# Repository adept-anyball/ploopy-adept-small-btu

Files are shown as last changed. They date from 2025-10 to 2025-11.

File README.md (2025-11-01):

# ploopy-adept-small-btu

> [!TIP]
> Making these models take time and investment. I would like to keep them free, so if you like them, please consider to [buy me a coffee](https://www.paypal.com/donate/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)

A small Ploopy Adept case with BTU bearings



I really like the Ploopy Adept hardware, but I wanted something smaller and lower to use between the two parts of my split keyboard. So I created this case for the Ploopy Adept, which is pretty small and low.

There are 4 versions:

- [V1](./v1-deprecated/): for a 34mm trackball. This is the initial version and it is deprecated. I would not recommend going for it. I am just keeping it here in case anyone still needs it. It will go at some point.

- [V2](./v2/): for a 38.1mm (1.5 inch) trackball. This version is still good to use and it can also fit the 34mm trackball support from V3.

- [V3](./v3/): which has trackball supports for both 34mm and 38.1mm trackballs. It is somewhat the same as V2, but with aesthetical improvements and slight improvements on the buttons too. In V3, the top and bottom of the case are the same, whether you choose to use a 34mm or a 38.1mm trackball, but you need to choose the correct track ball support.

- [V4 Slim](./v4/): which has trackball supports for both 34mm and 38.1mm trackballs. It is a much slimmer version of the v3, with aesthetical improvements e.g. all front buttons have the same size. The top and bottom of the case are the same, whether you choose to use a 34mm or a 38.1mm trackball, but you need to choose the correct track ball support.

- [V5 Slim Angled](./v5/): which has trackball supports for both 34mm trackballs. It builds on the V4, but has a 3 degree angle, which improves the buttons a lot.

I would obviously recommend going for the V5, but it is up to you to choose. You can find assembly instructions by browsing into the folder of each of the versions.

If you would like to user other bearings instead of BTUs, there are adapters available [here](https://github.com/adept-anyball/mod/tree/master/adapters).

Enjoy it! Feedback and contributions are very welcome.

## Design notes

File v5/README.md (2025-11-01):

# V5- SLIM - ANGLED - 34mm trackball

It is essentially the same as the v4, so all the same instructions apply.

The differences are from this and the v4 slim flat version are:

- It has a 3 degree angle, so the front buttons are slightly higher
- The buttons are improved: more stable and less dead areas

> [!IMPORTANT]
> The STEP and STL files contain top, bottom and ball support for a 34mm ball.
> So, please remember to split the into objects before printing

I didn't have time to create a 38mm ball support yet, not sure if it will be done and not when.
For now, if you want to use a 38mm ball, you can use the 38mm trackball support from the v4 slim.

There are 2 versions of the v5:

- v5-slim-angled-34mm-full: a more squared versions, with the same screw style of the v4

> [!IMPORTANT]
> The **v5-slim-angled-34mm-rounded-full** requires different screws. **It uses 4x M2.5x7mm screws**.

- v5-slim-angled-34mm-rounded-full: improved buttons, screws on the bottom (instead of on the sides) and more rounded corners.

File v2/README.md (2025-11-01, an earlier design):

# V2 - 38.1mm trackball (1.5 inch)



This design consists of 4 parts, see the mechanicals section for the explanation. It prints without supports and require minimal assembly.
Even though the top part consists of 2 separate parts, it looks like a unibody part after assembly.

## Mechanicals



1. v2-38mm-top-buttons.step: the top frame with buttons and a cut-out for the track ball support insert (part #2)
2. v2-38mm-top-trackball.step: the trackball insert where the bearings and the trackball should be placed. It fits in the cut-out of the part #1
3. v2-38mm-bottom.step: the bottom part of the case, where the pcb should be placed
4. (OPTIONAL) v2-38mm-cover-keycaps.step: a cover to the top, so you can add another finish to the top of the trackball and keycaps. These can be printed in different colors for some extra personalization and/or with a smaller layer height for a smoother surface :)

## Printing instructions/remarks

**The models print without the need of any support. Using supports will likely ruin the print, unless you really know what you are doing!**

I have printed it in both PLA and PETG and both work fine. I recommended using a layer height of 0.2mm.

Part #1 should be printed with the buttons facing the build plate (so upside-down), and the remaining parts should be printed in the regular orientation.

## BoM

- [A Ploopy Adept kit](https://ploopy.co/shop/adept-trackball-full-kit/)
- 4 M2 x 4mm thread inserts. I used [these ones](https://www.amazon.de/dp/B088QJG676/ref=pe_27091401_487027711_TE_SCE_dp_i1?th=1)
- 4 M2 x 10mm countersunk screws. I used [these ones](https://www.amazon.de/-/en/gp/product/B0D6QXRH6H/ref=ppx_od_dt_b_asin_title_s00?ie=UTF8&th=1)
- A 38.1mm trackball (1.5 inch). I have used my Ploopy Nano trackball. You can either buy a billiard ball or something more fit for purpose like this ones from [gamingtrackball](https://www.gamingtrackball.com/products/yellow-and-silver-add-on-balls)
- 3 BTU bearings [KU-B8-OFK R053010810](https://store.boschrexroth.com/BALL-TRANSFER-UNIT_R053010810?cclcl=en_MY)
- (OPTIONAL) Superglue to put some of the parts together

## Assembly

See Mechanicals section above for the part numbers.

1. Print all the parts
2. (OPTIONAL) Glue part #4 to part #1
3. Insert the 3 BTU bearings on part #2. There is some clearance, so you should not need to push very hard, only a bit of force is necessary.
4. Insert part #2 into the cut-out of part #1, making sure that the flat part of the optics cut-out is the round edge of the case (see picture below). Make sure that the bottom aligns perfectly. The part should stay in place, but you may choose to glue them together, if you prefer.



5. Insert the 4 thread inserts in the 4 holes on the corners of the bottom of part #1, using a heat-insertion tool or a soldering iron. I would recommend a proper heat-insertion tool like [this one](https://www.amazon.de/dp/B0C5CC2QB9/ref=pe_27091401_487027711_TE_SCE_dp_i1), since these thread inserts are quite small
6. Place the PCB in the sunken area of part #3
7. Place the top part over the bottom part making sure that the optics are aligned correctly. The bottom part has some small guides that should help placing the top correctly and holding it in place.
8. Screw the bottom to the top. Start by screwing all the screws half in and then tighten them up.

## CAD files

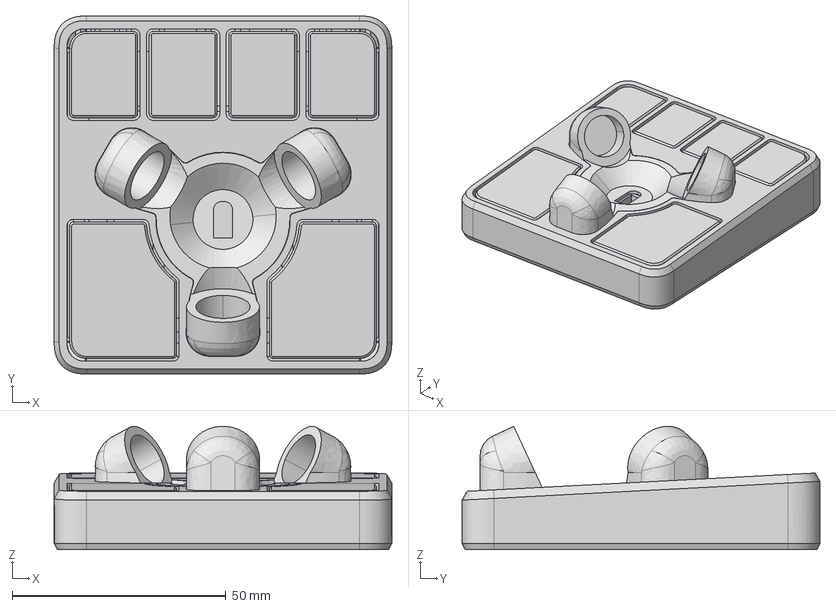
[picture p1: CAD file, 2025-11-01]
v5/v5-slim-angled-34mm-rounded-full.step
79.0 x 83.8 x 28.9 mm

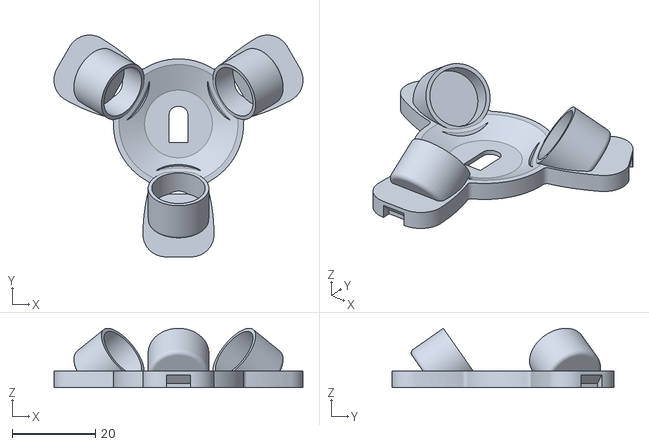
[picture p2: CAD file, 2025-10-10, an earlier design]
v4/generation script/trackball support generator - bosch btu, 21.8mm deflected.stl
59.8 x 53.3 x 14.3

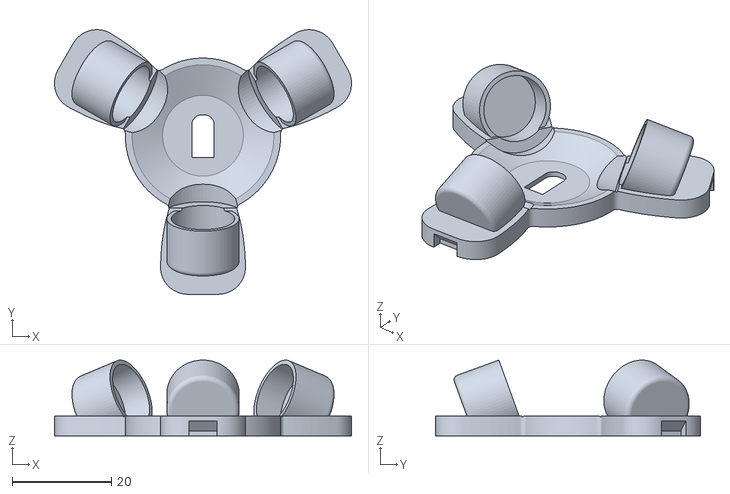
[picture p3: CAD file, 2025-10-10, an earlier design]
v4/generation script/trackball support generator - bosch btu, 25mm ball.stl
59.8 x 53.3 x 15.3

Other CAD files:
v5/v5-slim-angled-34mm-full.step
v4/generation script/trackball support generator.scad
v5/v5-slim-angled-34mm-full.stl
v5/v5-slim-angled-34mm-rounded-full.stl

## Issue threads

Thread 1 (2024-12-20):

Not an issue, just wanted to thank you for this

whosdev, 2024-12-20:
Heya, Not an issue at all I just wanted to thank you for this awesome job. I recently bought an Adept, and while I loved it, I found it too tall for my hand, somehow, I loved this version you made. Is there a way to "make room" to use the 44mm ball that comes with it while still being somewhat slim? also which BTU did you use?

fabricio-bastian, 2024-12-20:
Hi there. Glad to hear that you liked it :)
I did consider using a larger ball while I was designing it. My choice of using a smaller ball was a bit about aesthetics, but also because, in my personal opinion, the 44mm ball has too much momentum on the BTUs. Also, it would compromise a bit on the usability of the buttons, because there is not that much room.
I think that the perfect size would be the ploopy nano trackball. Which is probably where I'm going next with this (I don't know when though :)). I just found it a bit hard to source trackballs on that size that look nice...

whosdev, 2024-12-20:
I see, thank you again! I'll both print this one and try to change the ball size, I do have a few 34mm perixx here as well, But never used the btu's so I've no idea on how it affect the momentum.
I don't mind the trackball getting a bit bigger overall (I mean, in size, but not in height heh).

fabricio-bastian, 2024-12-20:
Sounds great. Do you want access to the design file? I would love to see the results if you play with the design :)

I have used onshape and I can share it with you, so you can play with it. The CAD history is not particularly clean though 😅.

If you go for the 44mm ball, you will likely get something that is about as tall as the original Adept, with the exception of the front buttons, since this design is not slanted as the original is.

whosdev, 2024-12-21:
Yeah sure! I would love to have the design files! But now it makes sense, maybe the ball would be TOO high, and it wouldn't be that much usable, hmmmmmmmm, now I am not sure If it's a great idea! I was planning on using chinese BTU, which aren't that great, but are the ones I can buy hahahha. So I think maybe with a bigger ball, it won't have that much momentum.
 But I wasn't thinking about the height of the ball and how hard/easy it will be to push the buttons. damn, I'm dumb.

fabriciobastian, 2025-01-04:
Hey again. I did a new version with a 1.5inch ball (same size as the nano), which you may like. I have uploaded the step files, which are easier to modify. The trackball is still quite low IMO, I can still use it in a natural hand position without any need for wrist rests. Check it out :)

Closed 2025-01-04.

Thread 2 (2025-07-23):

Feature Request: Different Ball sizes

vaughnmonkey, 2025-07-23:
I love your design and was wondering if you'd be game/able to make a version that would fit a pool-ball (2.25in/57.15mm). I'll eventually try to make this variation myself but figured if you're model was parametric then maybe it would be a simple adjustment to make and share.

fabricio-bastian, 2025-07-23:
Hey. Thanks for the nice words and suggestion. The design isn't parametric, because the purpose was minimization and low-profile.
I have thought of increasing the ball size, but it won't work well because the front buttons will be hard to reach beyond 38mm.
With the Adept PCB, larger balls do require that the case is angled.
A 57mm ball is too big even for the original case.
These are my thoughts, may I get to know yours :)?

fabriciobastian, 2025-08-12:
Closing because of inactivity. I have no plans on changing this design for larger ball sized atm.

Closed 2025-08-12.

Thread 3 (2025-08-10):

STEP files giving UTF-8 error in OrcaSlicer

scatterthought, 2025-08-10:
Would you be able to upload STL files? When I import the v3 STEP files into OrcaSlicer, I get the following error:

"Component name(s) inside step file not in UTF8 format! Because of unsupported text encoding, garbage characters may appear!"

An older copy of PrusaSlicer (which I stopped using) just gives "invalid string position" for the error.

I also tried one of the v2 files and got the same errors.

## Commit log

2025-10-14 feat: add v4 angled
    [v4-slim-angled-34mm-full.step, v4-slim-angled-34mm-full.stl]
2025-11-01 feat: v5 slim angled
    [v5-slim-angled-34mm-full.step, v5-slim-angled-34mm-full.stl, v5-slim-angled-34mm-rounded-full.step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]
